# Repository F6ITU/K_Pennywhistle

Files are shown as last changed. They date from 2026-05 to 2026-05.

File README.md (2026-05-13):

# K\_Pennywhistle

**A 20W HF amplifier by KE9H**

Pennywhistle is a linear amplifier based on a pair of Mitsubishi FET (RD16HHF1 or RD15HVF1) that was originally (17 years ago) used to boost the output power of the very first SDRs using the Hermes board.

Marketed as a kit by the TAPR, this amplifier—which is very easy to build—has long been out of production.

In the meantime, numerous variations have emerged, notably the famous G6ALU, which was used in Picastar transceivers.

This same amplifier is also integrated into the filter board of the Anan 100 series and serves as  driver for the RD100HHF1 output stage.

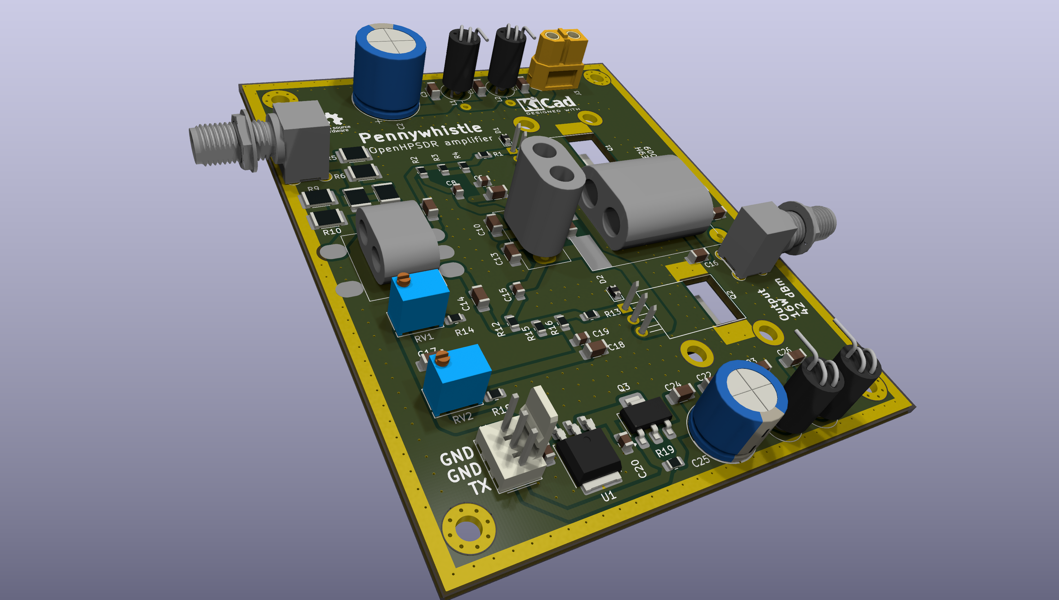
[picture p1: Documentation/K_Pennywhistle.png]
Pennywhistle, a 16W HF linear amplifier


Why build such a clone in 2026 ?

* Because this design is proven and has been built in the thousands
* To complete the collection of OpenHPSDR board clones already available on this GitHub repository
* Because it can deliver either 4 to 7 W with RD06HVF1 transistors or 15 to 20 W in its original version—power levels perfectly suited for driving a higher-power amplifier (Munin 1 to 4 series, Munin 100, Munin 400...)
* Because it can easily complement a "barefoot" SDR outputting 0.5 to 1 W
* And because it is also compatible with the Ajax pre-driver module

It should be added that, technically speaking, it would be preferable to build a push-pull circuit using LDMOS transistors, such as the AFT05MS003... but the void left by the closure of NXP’s production facilities for high-frequency transistors and the resulting component shortage mean that a return —even a temporary one— to older technologies is far from unreasonable.

Finally, this amplifier is probably one of the simplest circuits available, allowing beginners to tackle building a linear amplifier without spending a fortune.

This project is licensed under the TAPR Open Hardware License and is the result of the work of Graham Haddock KE9H

It's design has been made using Kicad 10 opensource EDA.

Ibom can be downloaded from https://github.com/F6ITU/K\_Pennywhistle/blob/main/bom/ibom.html

All building and tuning instructions could be found in the original Pennywhistle documentation (https://github.com/TAPR/OpenHPSDR-SVN/blob/master/PennyWhistle/Documentation/PennyWhistle%20Manual%20V1.2.pdf)

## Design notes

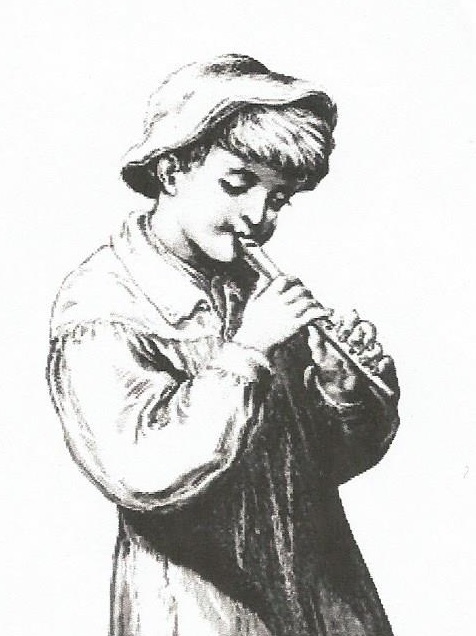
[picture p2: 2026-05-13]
Documentation/whistle.jpg

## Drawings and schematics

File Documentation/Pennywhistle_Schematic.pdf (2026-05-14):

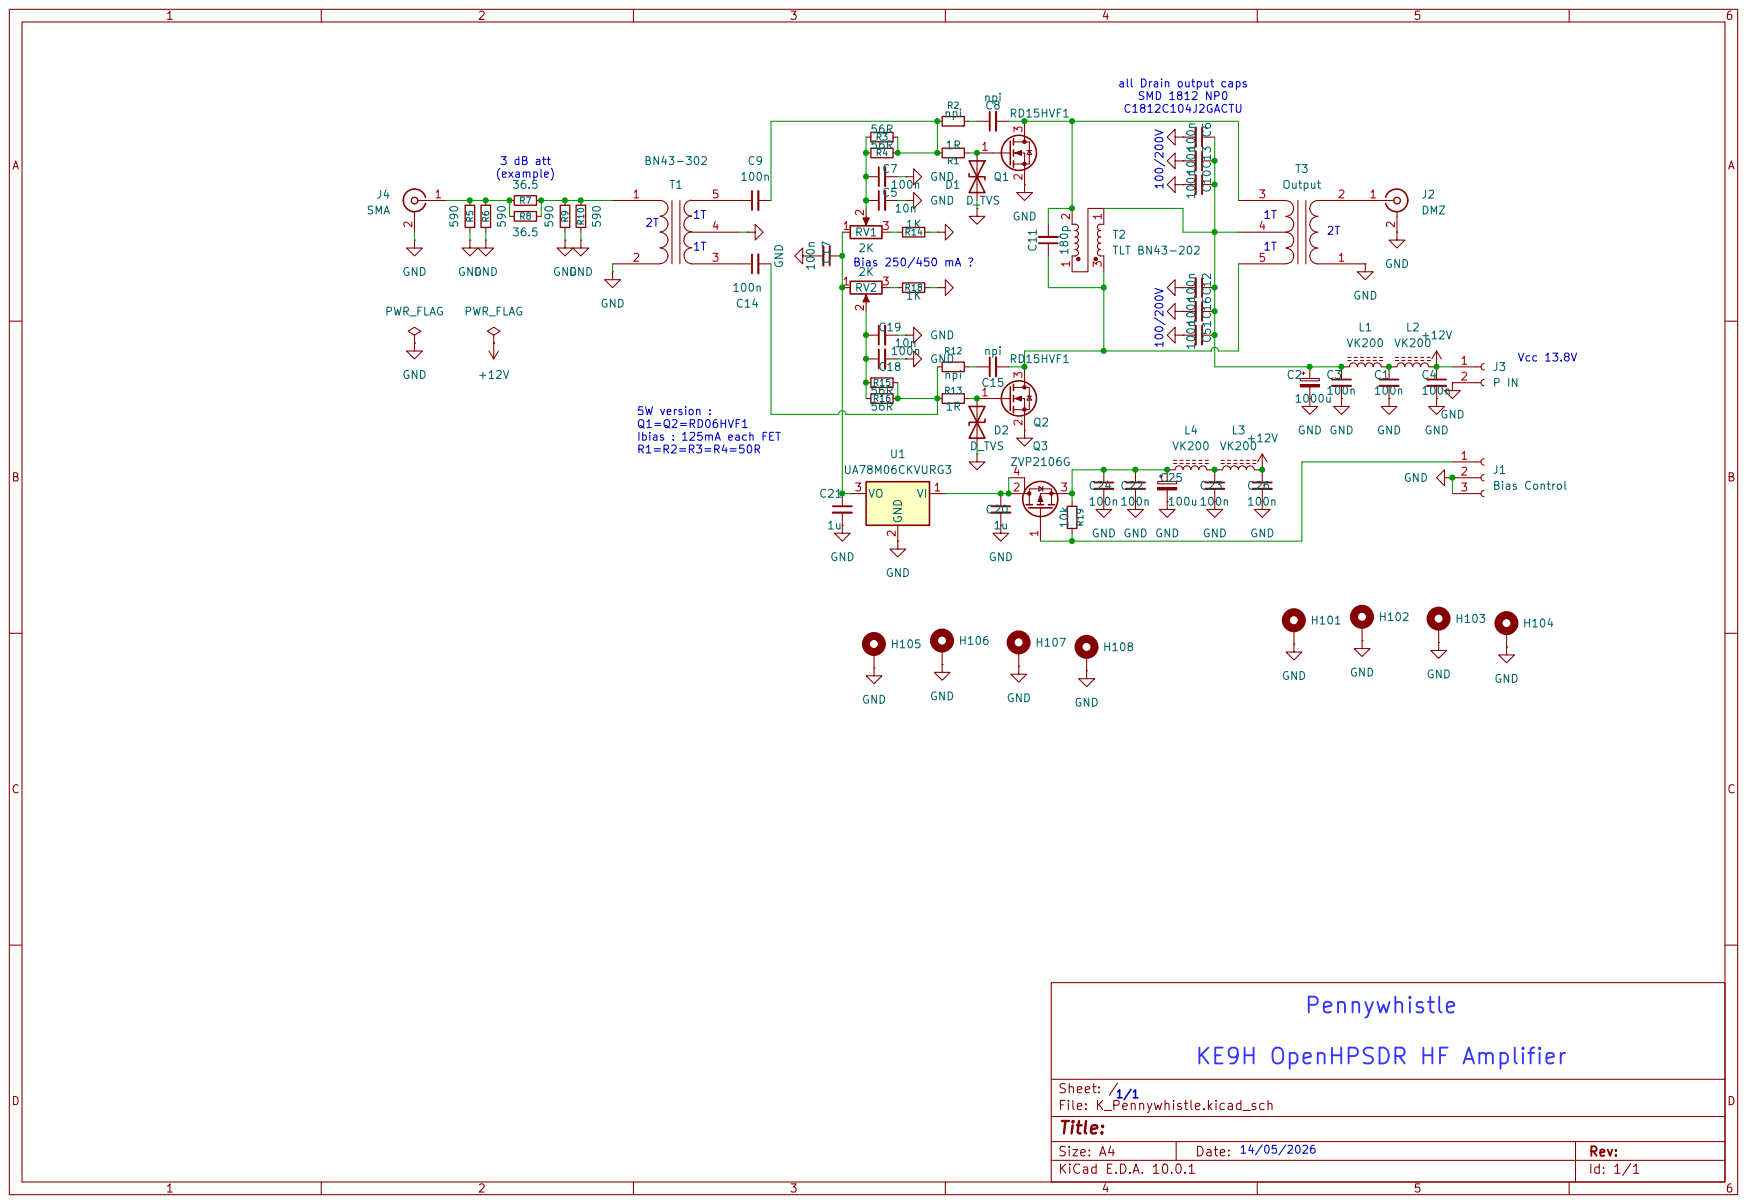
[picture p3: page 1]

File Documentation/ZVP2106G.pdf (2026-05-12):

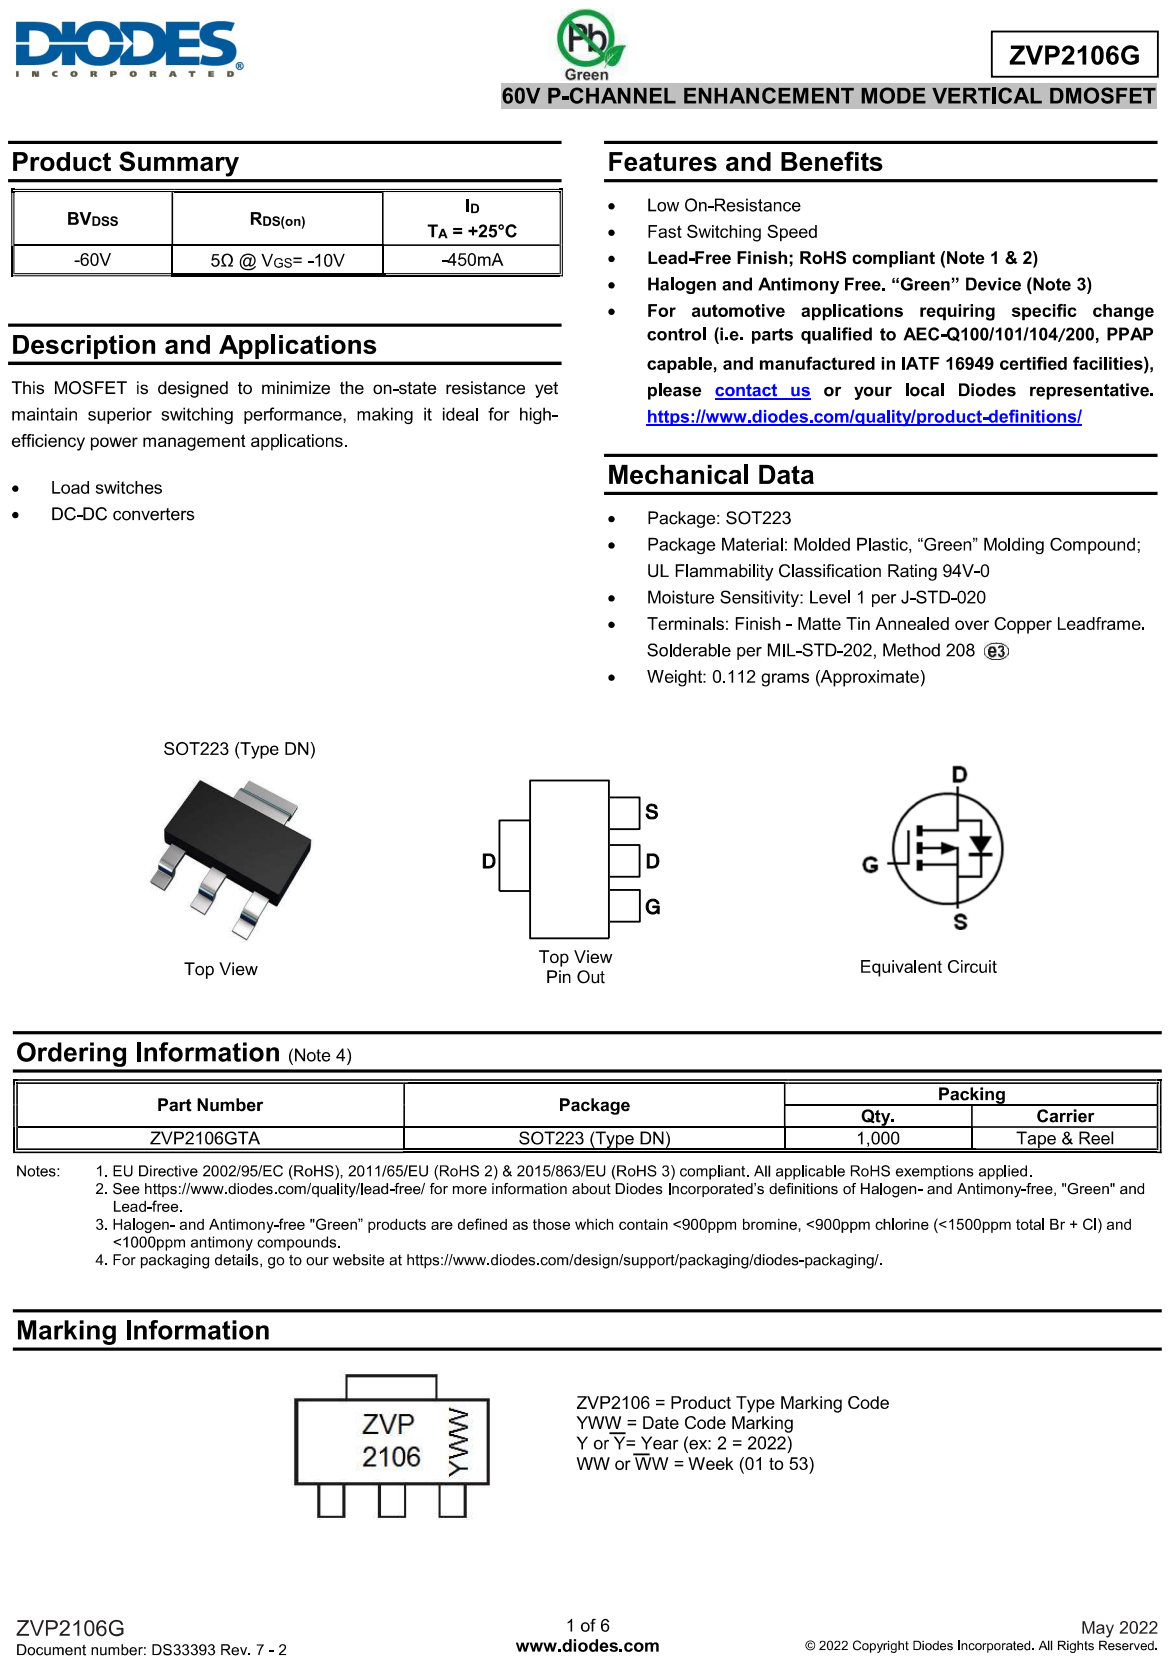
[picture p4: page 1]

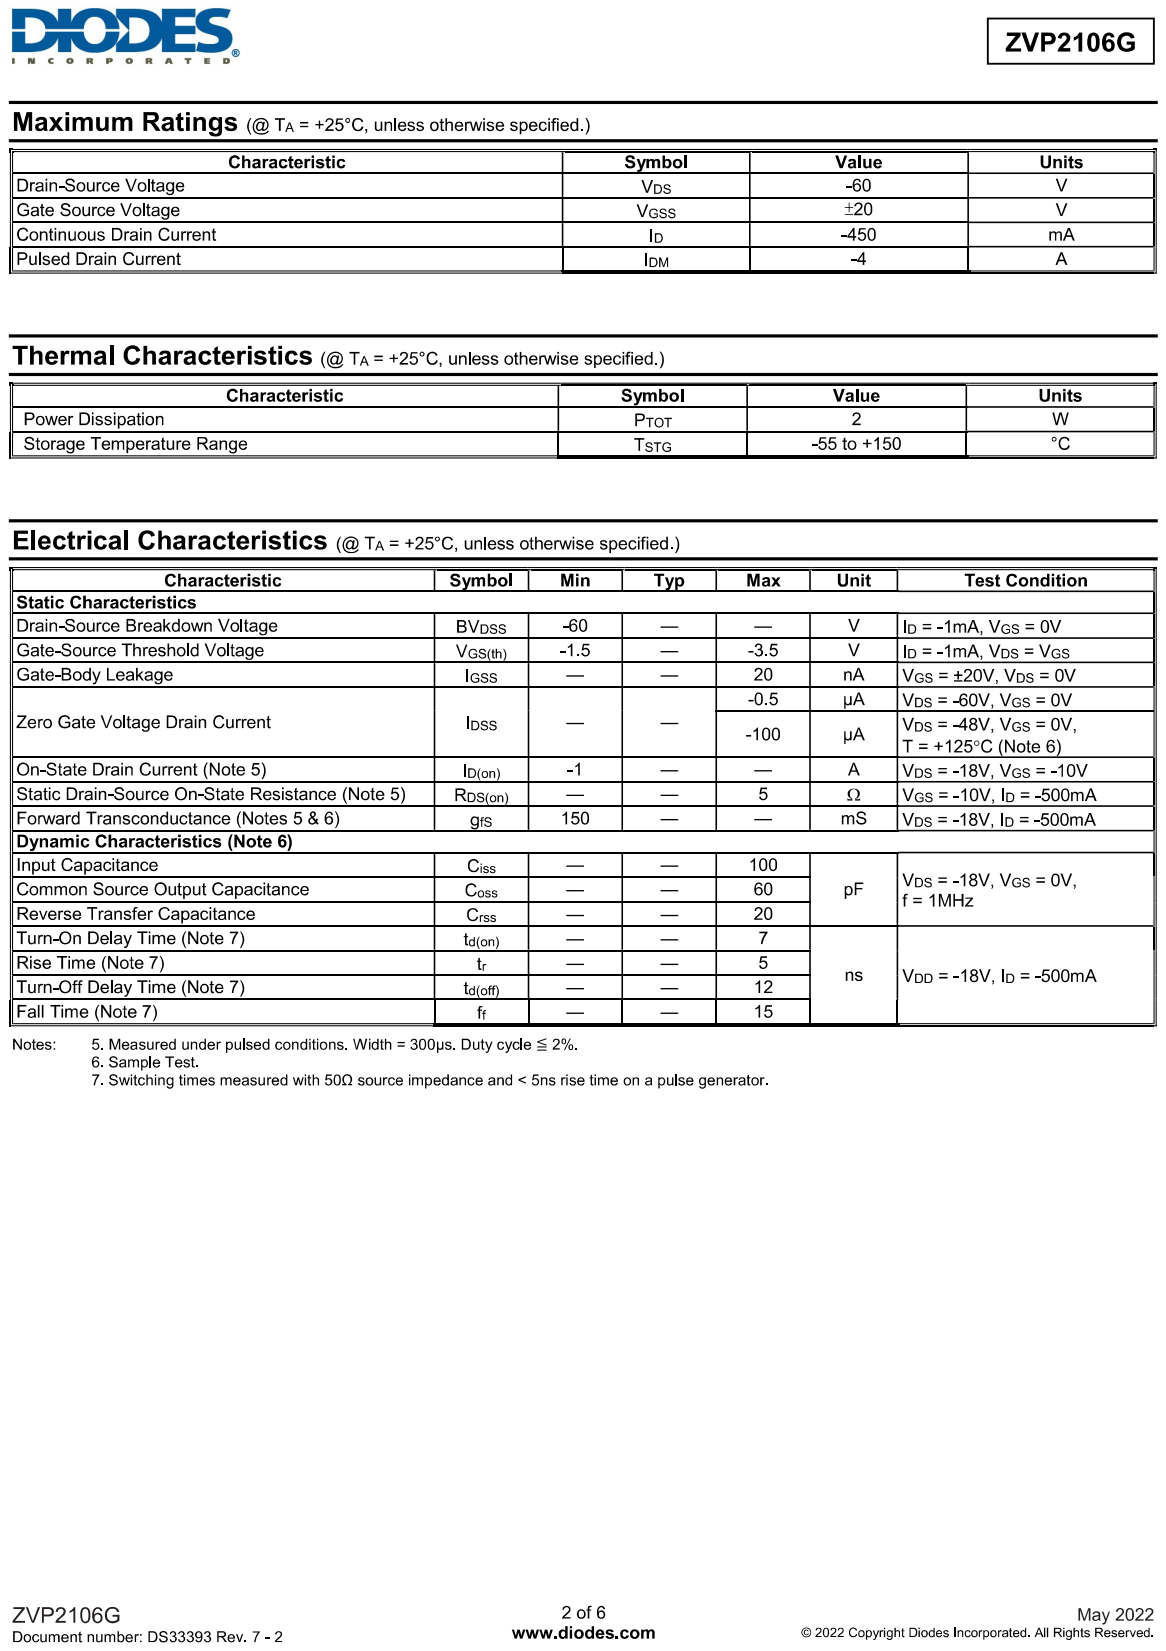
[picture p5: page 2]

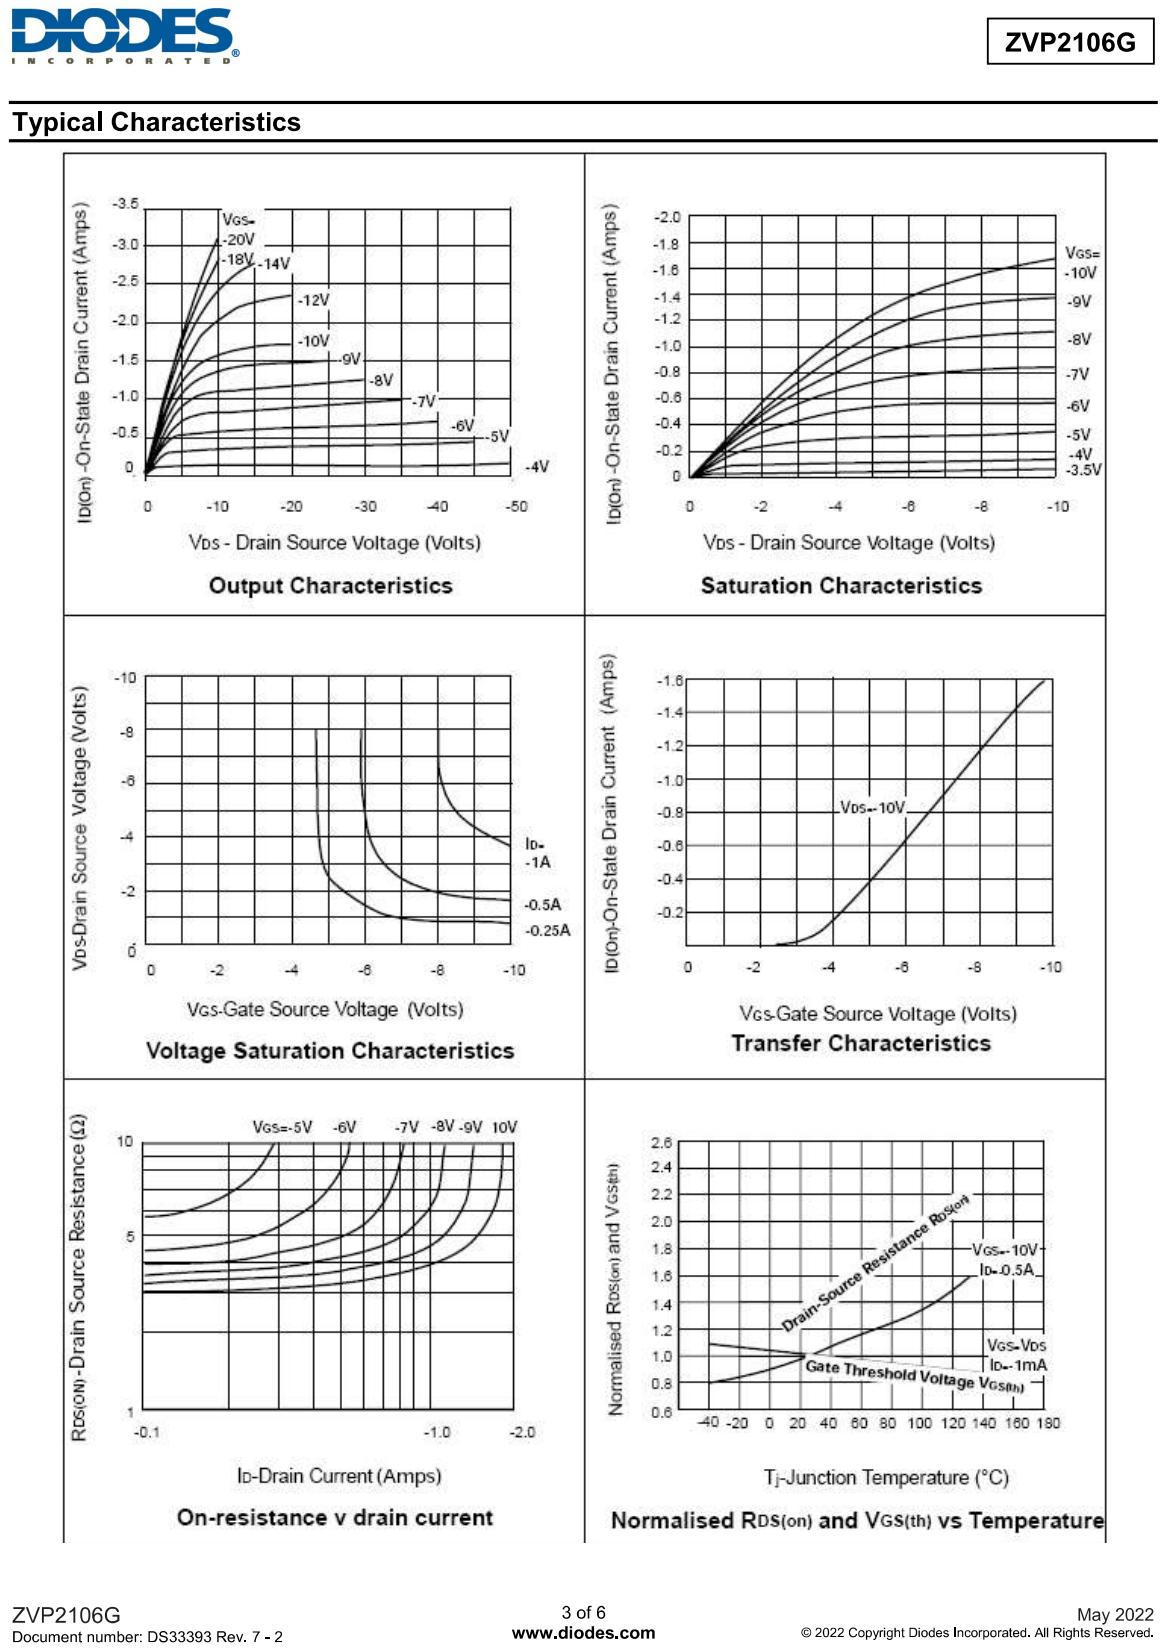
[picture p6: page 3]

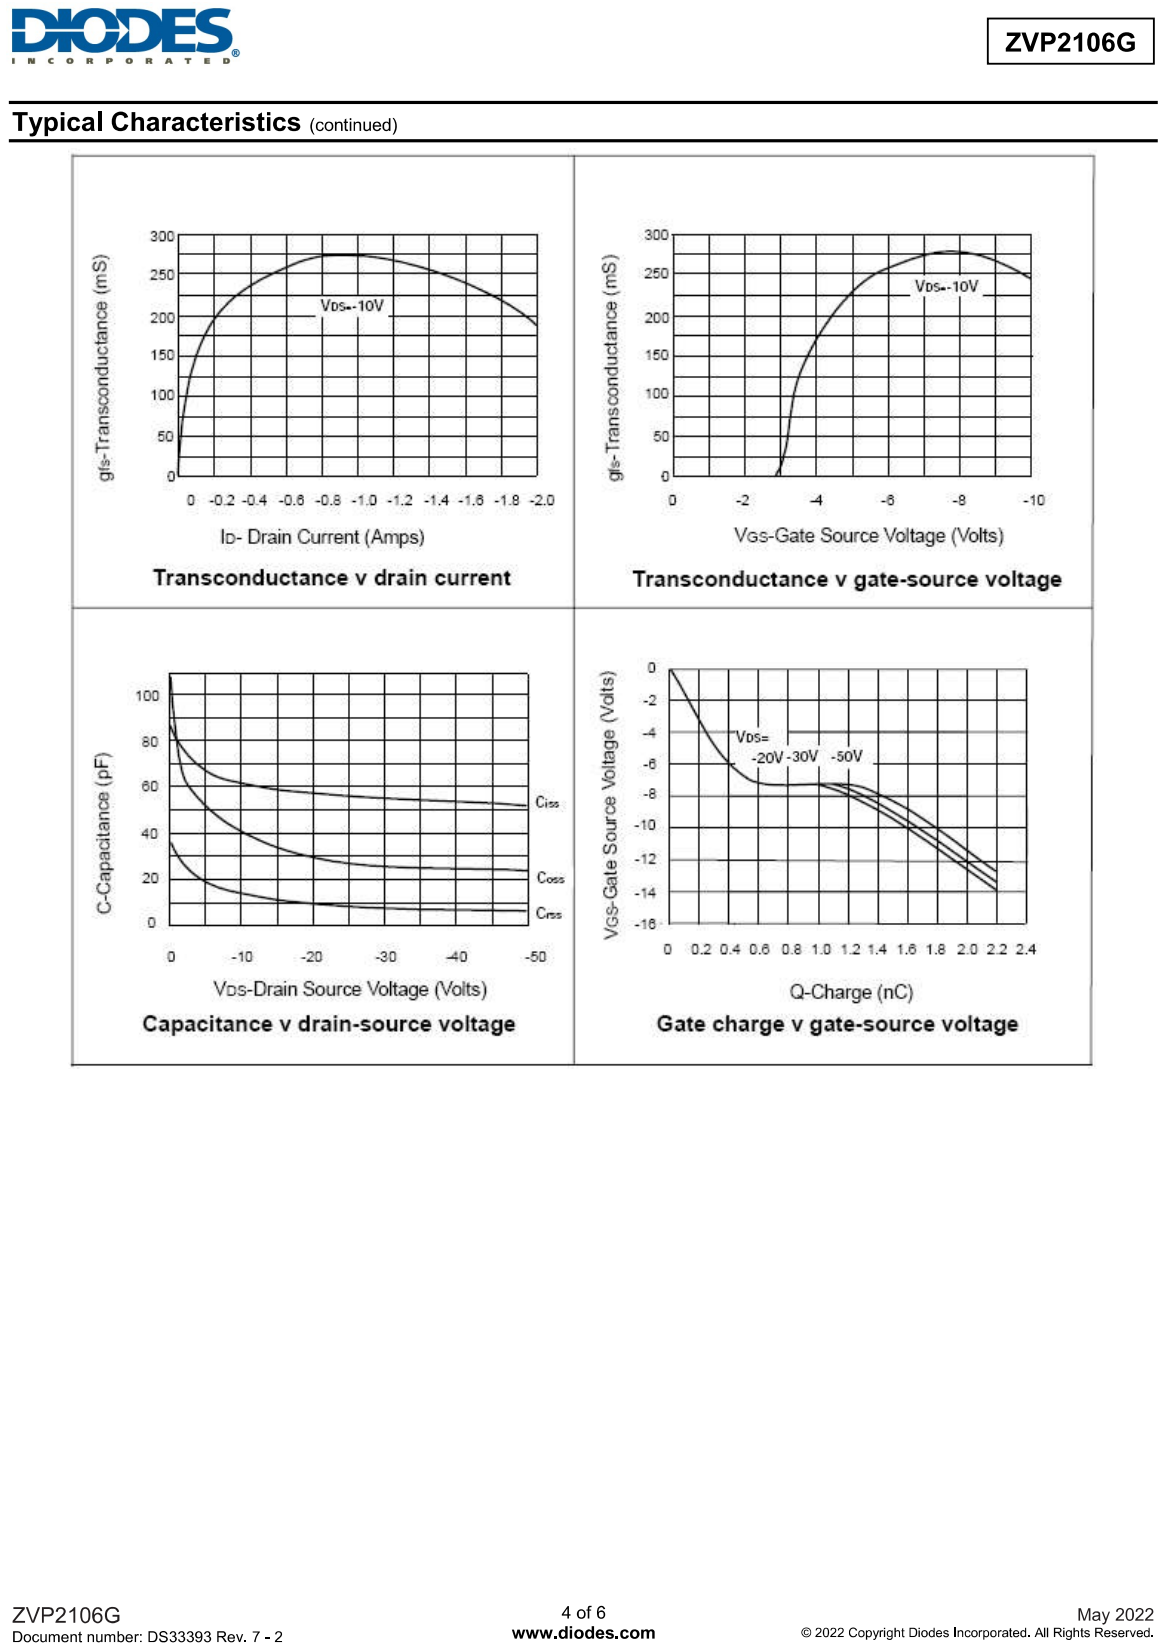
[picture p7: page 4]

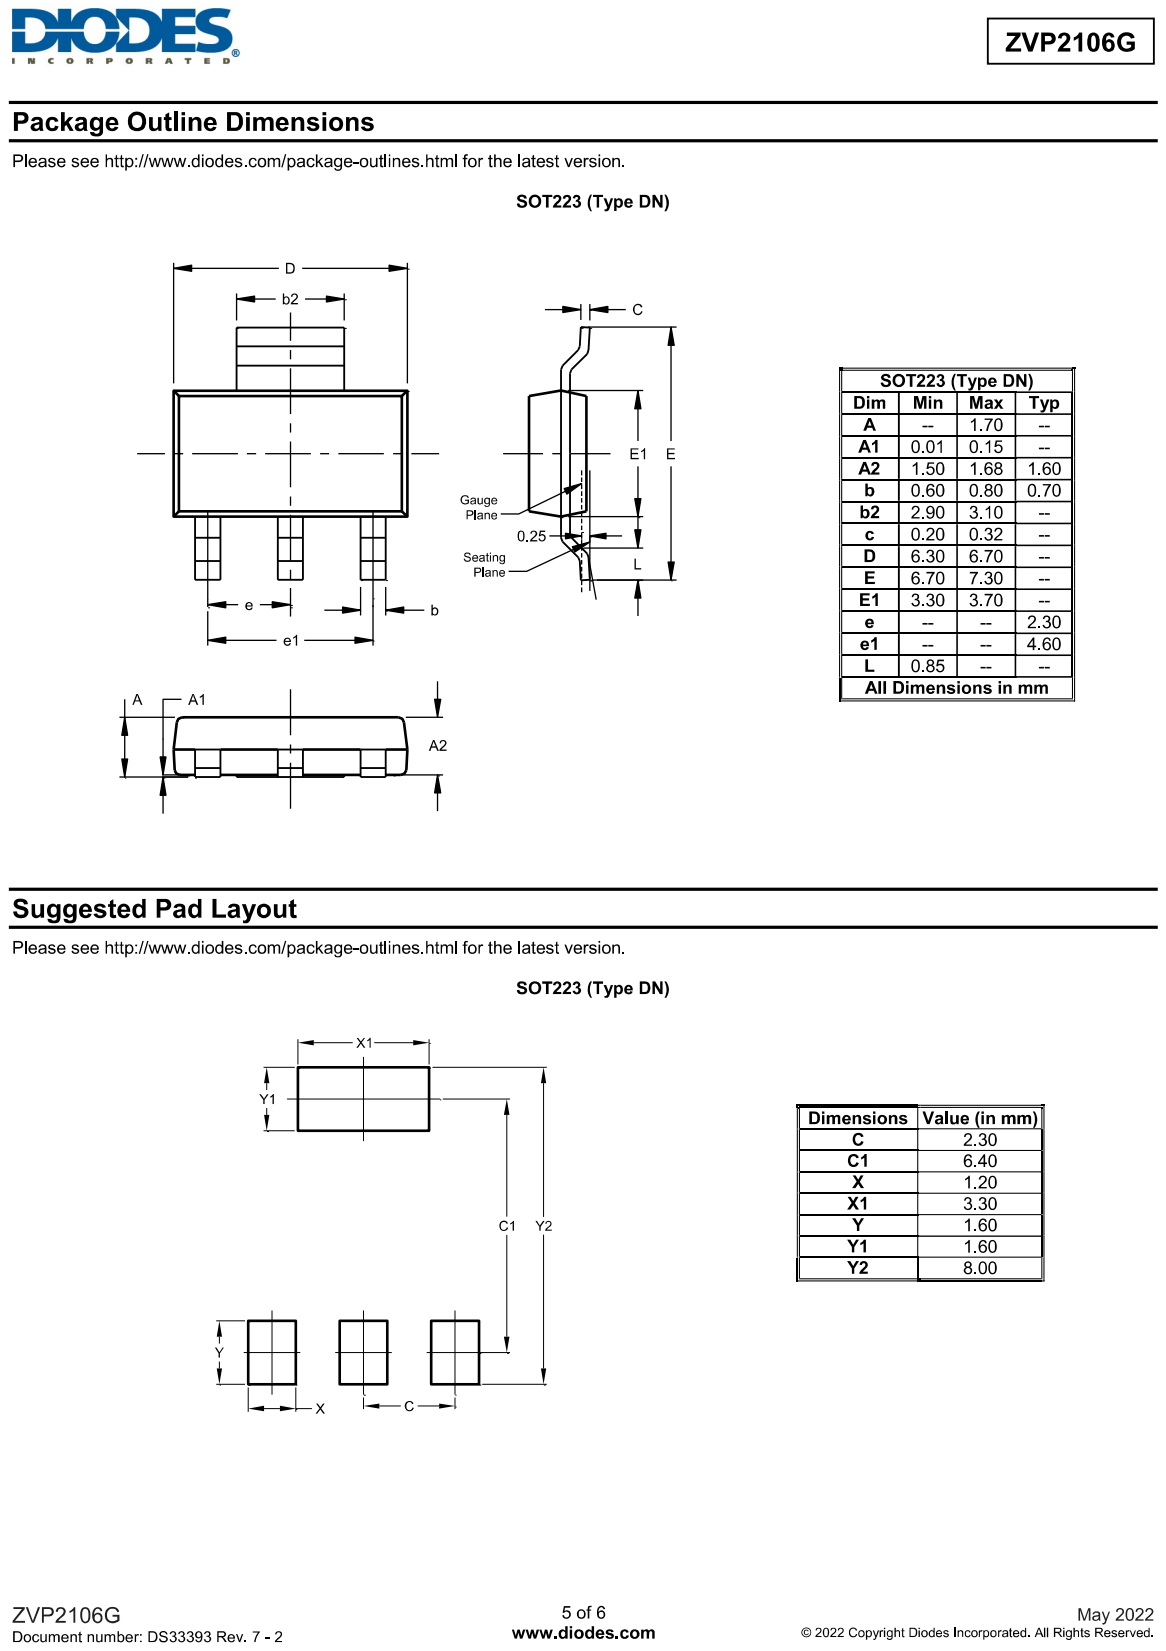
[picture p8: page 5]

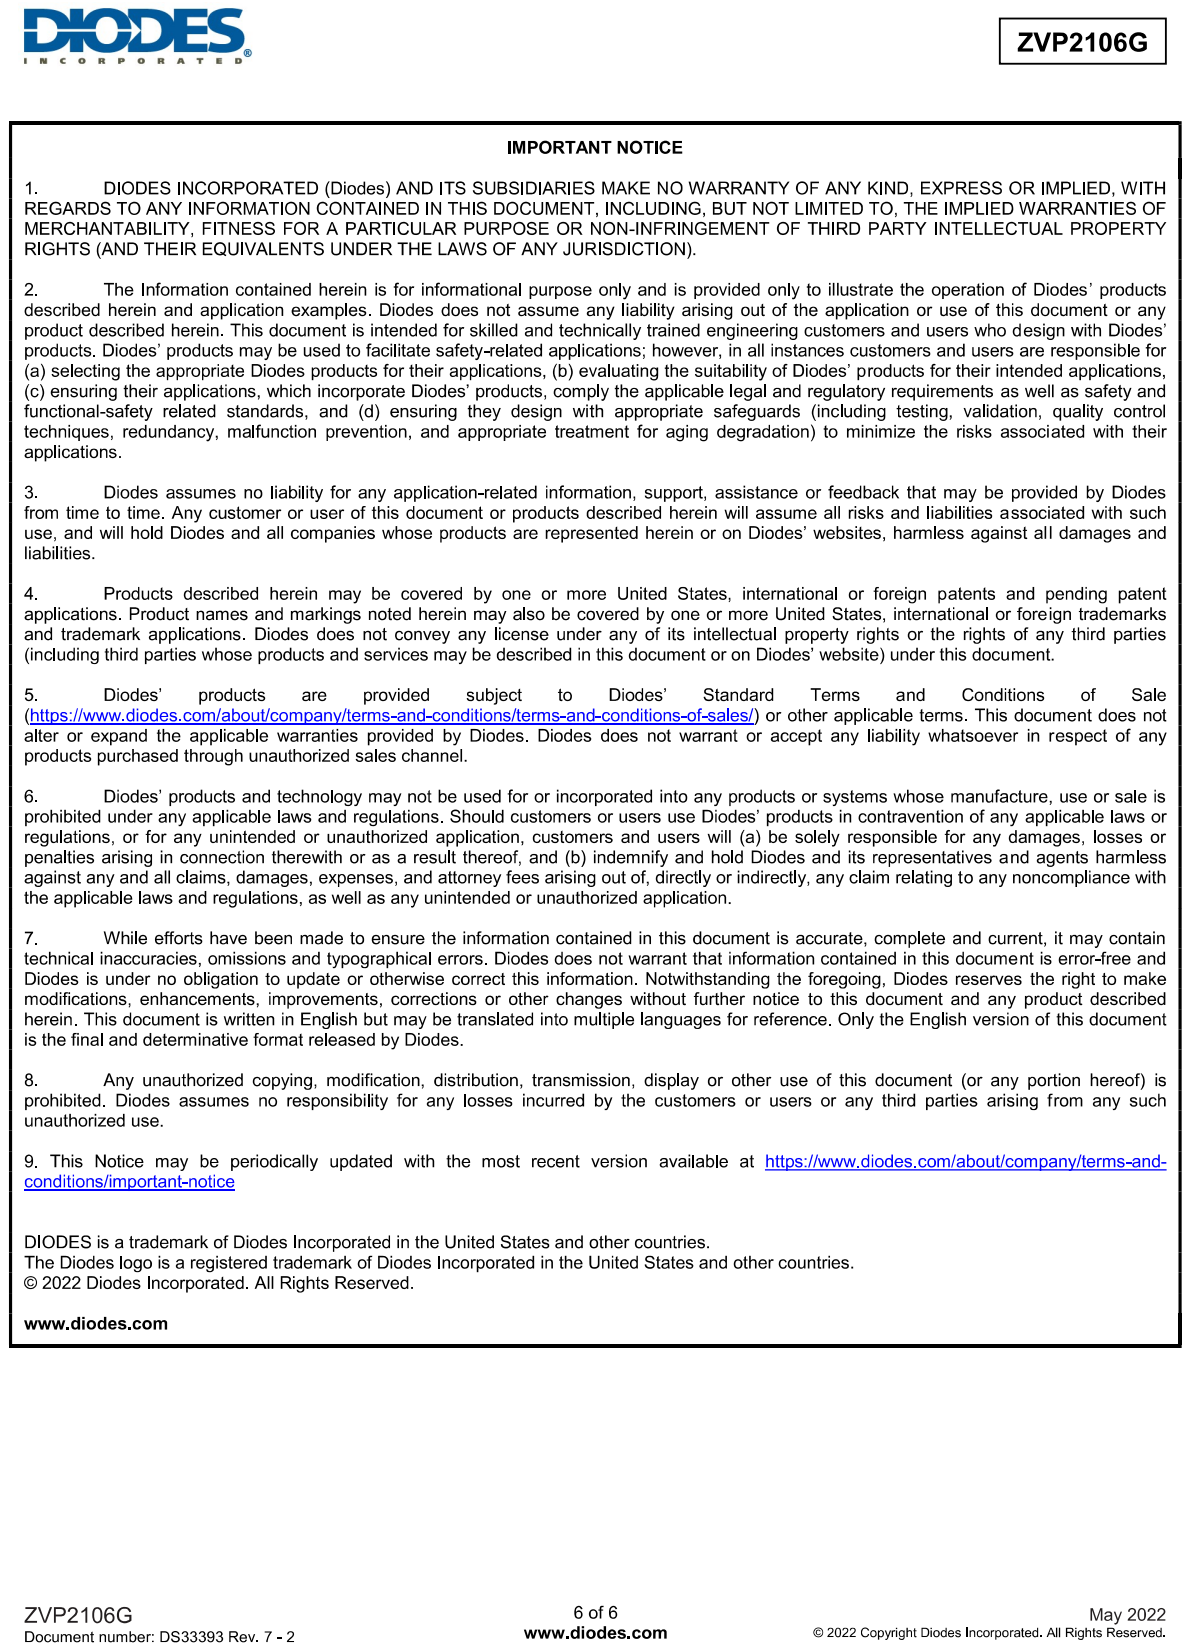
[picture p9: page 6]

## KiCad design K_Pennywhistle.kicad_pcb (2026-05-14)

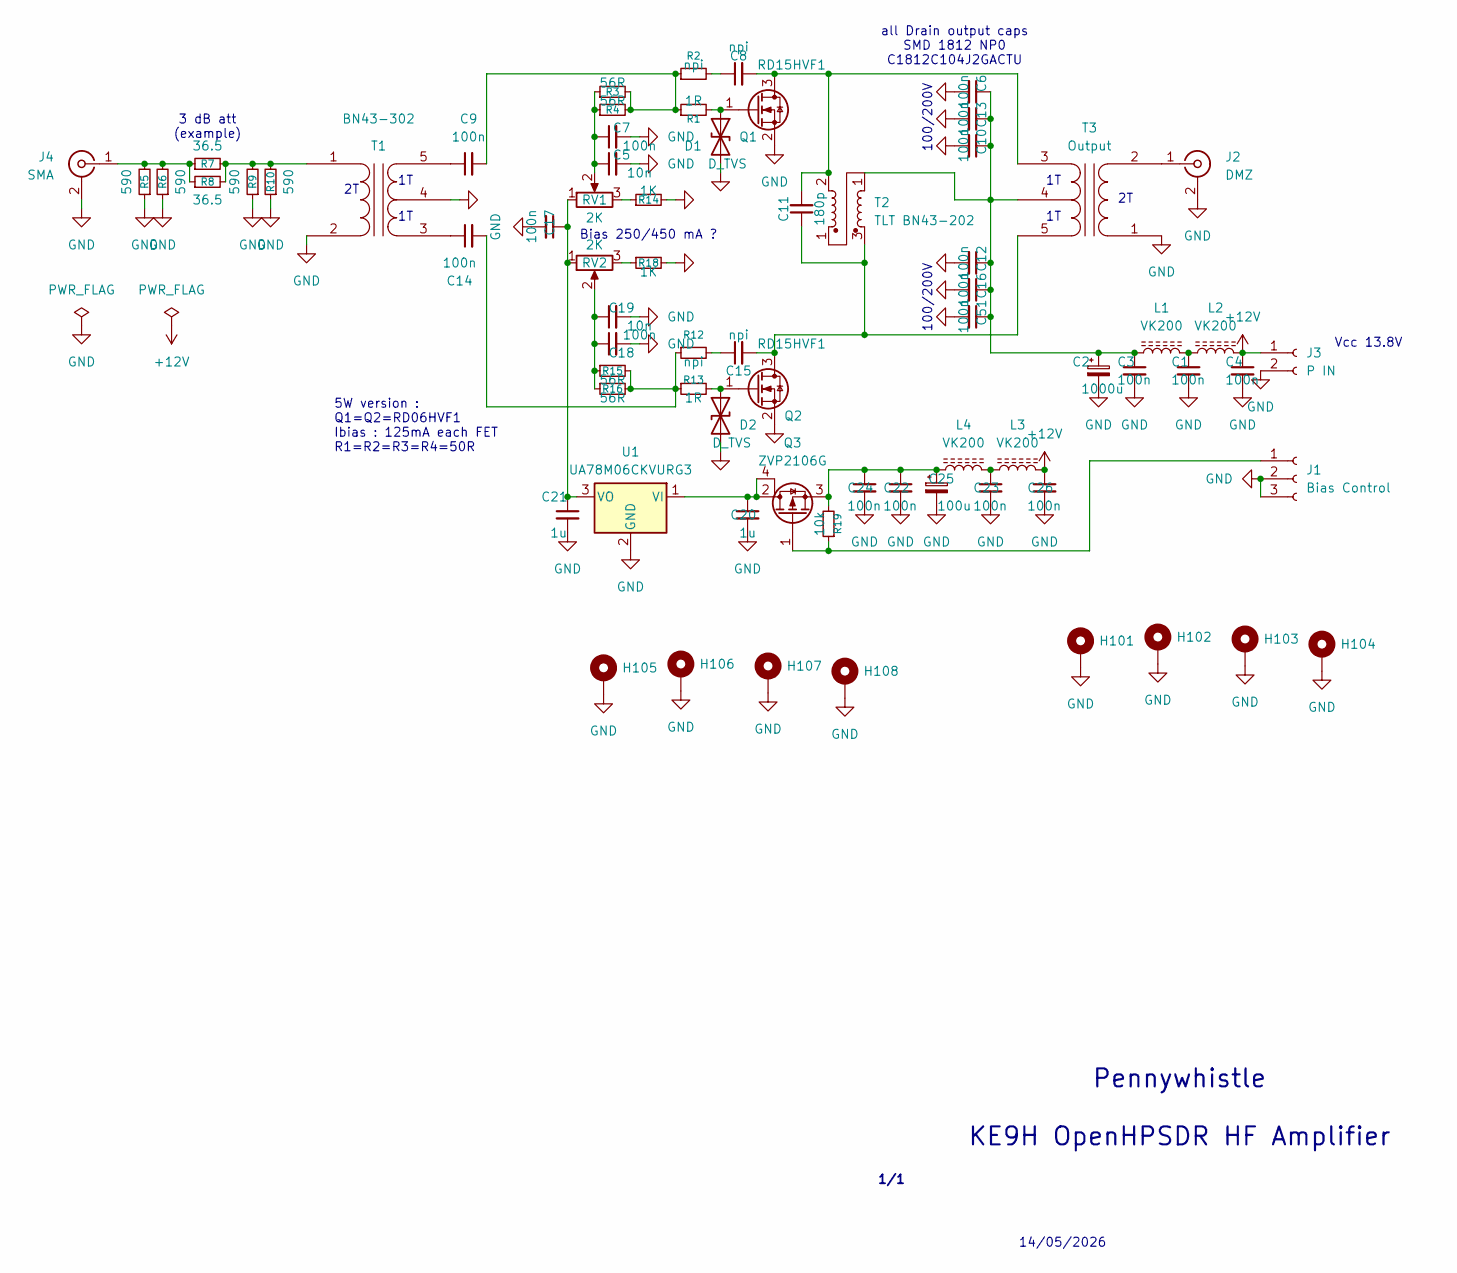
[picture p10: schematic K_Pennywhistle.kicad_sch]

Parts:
C1, C3, C4, C6, C7, C9, C10, C12, C13, C14, C16, C17, C18, C22, C23, C24, C26, C51: 100n; C_1206_3216Metric_Pad1.33x1.80mm_HandSolder
C2: 1000u; CP_Radial_D12.5mm_P7.50mm
C5, C19: 10n; C_0805_2012Metric_Pad1.18x1.45mm_HandSolder
C8, C15: npi; C_0805_2012Metric_Pad1.18x1.45mm_HandSolder
C11: 180p; C_1206_3216Metric_Pad1.33x1.80mm_HandSolder
C20, C21: 1u; C_0805_2012Metric_Pad1.18x1.45mm_HandSolder
C25: 100u; CP_Radial_D10.0mm_P5.00mm
D1, D2: D_TVS; D_0805_2012Metric
H101, H102, H103, H104: MountingHole_Pad; MountingHole_3.2mm_M3_Pad_Via
H105, H106, H107, H108: MountingHole_Pad; MountingHole_3.2mm_M3_ISO14580_Pad_TopBottom
J1: Bias Control; Molex_KK-254_AE-6410-03A_1x03_P2.54mm_Vertical
J2: DMZ; SMA_PINS
J3: P IN; AMASS_XT30U-F_1x02_P5.0mm_Vertical
J4: SMA; SMA_PINS
L1, L2, L3, L4: VK200; L_Axial_L12.8mm_D5.8mm_P5.08mm_Vertical_Fastron_HBCC
Q1, Q2: RD15HVF1; TO-220-3_Horizontal_TabDown
Q3: ZVP2106G; SOT-223-3_TabPin2
R1, R13: 1R; R_0805_2012Metric_Pad1.20x1.40mm_HandSolder
R2, R12: npi; R_0805_2012Metric_Pad1.20x1.40mm_HandSolder
R3, R4, R15, R16: 56R; R_0805_2012Metric_Pad1.20x1.40mm_HandSolder
R5, R6, R9, R10: 590; R_1812_4532Metric_Pad1.30x3.40mm_HandSolder
R7, R8: 36.5; R_1812_4532Metric_Pad1.30x3.40mm_HandSolder
R14, R18: 1K; R_0805_2012Metric_Pad1.20x1.40mm_HandSolder
R19: 10k; R_0805_2012Metric_Pad1.20x1.40mm_HandSolder
RV1, RV2: 2K; Potentiometer_Bourns_3266W_Vertical
T1: BN43-302; BN-61-202
T2: TLT BN43-202; BN-61-202
T3: Output; BN-61-202
U1: UA78M06CKVURG3; TO-252-3_TabPin2

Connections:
+12V: C4.1, C26.1, J3.1, L2.2, L3.2
GND: C1.2, C2.2, C3.2, C4.2, C5.2, C6.2, C7.2, C10.2, C12.2, C13.2, C16.2, C17.2, C18.2, C19.2, C20.2, C21.2, C22.2, C23.2, C24.2, C25.2, C26.2, C51.2, D1.2 (A2), D2.2 (A2), H101.1 (1_1), H102.1 (1_1), H103.1 (1_1), H104.1 (1_1), H105.1 (1_1), H106.1 (1_1), H107.1 (1_1), H108.1 (1_1), J1.2, J1.3, J2.2 (Ext), J3.2, J4.2 (Ext), Q1.2 (S), Q2.2 (S), R5.1, R6.1, R9.1, R10.1, R14.2, R18.2, T1.2 (AB), T1.4 (SC), T3.1 (AA), U1.2 (GND)
unnamed: C1.1, L1.2, L2.1
unnamed: C5.1, C7.1, R3.1, R4.1, RV1.2
unnamed: C8.1, R2.2
unnamed: C9.2, R1.1, R2.1, R3.2, R4.2
unnamed: C14.2, R12.1, R13.1, R15.2, R16.2
unnamed: C15.1, R12.2
unnamed: C18.1, C19.1, R15.1, R16.1, RV2.2
unnamed: C23.1, L3.1, L4.2
unnamed: D1.1 (A1), Q1.1 (G), R1.2
unnamed: D2.1 (A1), Q2.1 (G), R13.2
unnamed: J1.1, Q3.1 (G), R19.1
unnamed: J2.1 (In), T3.2 (AB)
unnamed: J4.1 (In), R5.2, R6.2, R7.1, R8.1
unnamed: C8.2, C11.2, Q1.3 (D), T2.2, T3.3 (SA)
unnamed: C11.1, C15.2, Q2.3 (D), T2.3, T3.5 (SB)
unnamed: C22.1, C24.1, C25.1, L4.1, Q3.3 (S), R19.2
unnamed: R14.1, RV1.3
unnamed: R18.1, RV2.3
unnamed: R7.2, R8.2, R9.2, R10.2, T1.1 (AA)
unnamed: C14.1, T1.3 (SA)
unnamed: C9.1, T1.5 (SB)
unnamed: C2.1, C3.1, C6.1, C10.1, C12.1, C13.1, C16.1, C51.1, L1.1, T2.1, T3.4 (SC)
unnamed: C20.1, Q3.2 (D), Q3.4 (D), U1.1 (VI)
unnamed: C17.1, C21.1, RV1.1, RV2.1, U1.3 (VO)

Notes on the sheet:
14/05/2026
Pennywhistle KE9H OpenHPSDR HF Amplifier
5W version : Q1=Q2=RD06HVF1 Ibias : 125mA each FET R1=R2=R3=R4=50R
100/200V
Vcc 13.8V
3 dB att (example)
Bias 250/450 mA ?
1/1
all Drain output caps SMD 1812 NP0 C1812C104J2GACTU

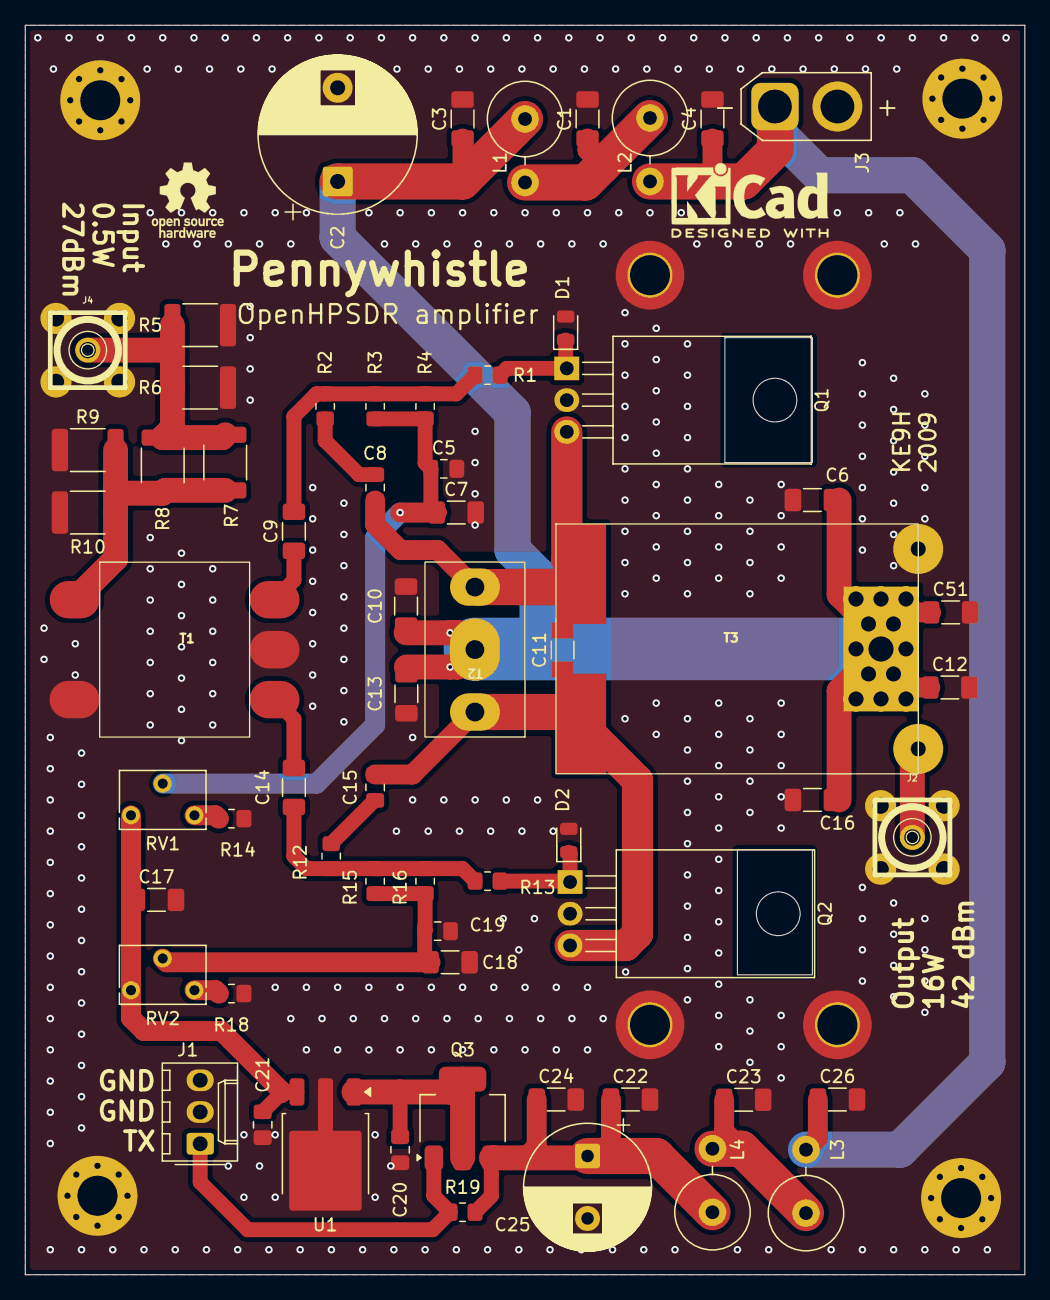
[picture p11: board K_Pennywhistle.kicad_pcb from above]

Board: 2 copper layers, 80.0 x 100.0 mm, 71 parts (0 on the bottom side), 26 nets.

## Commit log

2026-05-12 initial release, no iBom, no routing yet
    [K_Pennywhistle.kicad_pcb, K_Pennywhistle.kicad_sch]
2026-05-12 first routed draft, fix some errors
    [K_Pennywhistle.kicad_pcb, K_Pennywhistle.kicad_sch]
2026-05-13 near RTM, iBom and 3D image added
    [K_Pennywhistle.kicad_pcb, K_Pennywhistle.kicad_sch]
2026-05-13 RTM (at last!)
    [K_Pennywhistle.kicad_pcb]
2026-05-14 release, new Gerber, minor mods
    [K_Pennywhistle-B_Cu.gbl, K_Pennywhistle-B_Mask.gbs, K_Pennywhistle-B_Paste.gbp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]
2026-05-14 minor mods, new Gerber & iBom, schematic pdf,RTM
    [K_Pennywhistle-B_Cu.gbl, K_Pennywhistle-B_Mask.gbs, K_Pennywhistle-B_Paste.gbp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]
